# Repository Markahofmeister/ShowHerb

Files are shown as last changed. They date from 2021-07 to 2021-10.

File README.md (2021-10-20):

# ShowHerb 

ShowHerb is an automated garden watering system. It uses Adafruit's STEMMA I2C soil sensors, reporting soil moisture levels and temperature. 

The control structure uses an Arduino nano, as well as a TCA I2C multiplexer to allow up to 8 sensors to be added. The electromechanical irrigation valve is controlled by a 5V relay, also controlled by the Arduino.

## System Diagram: 

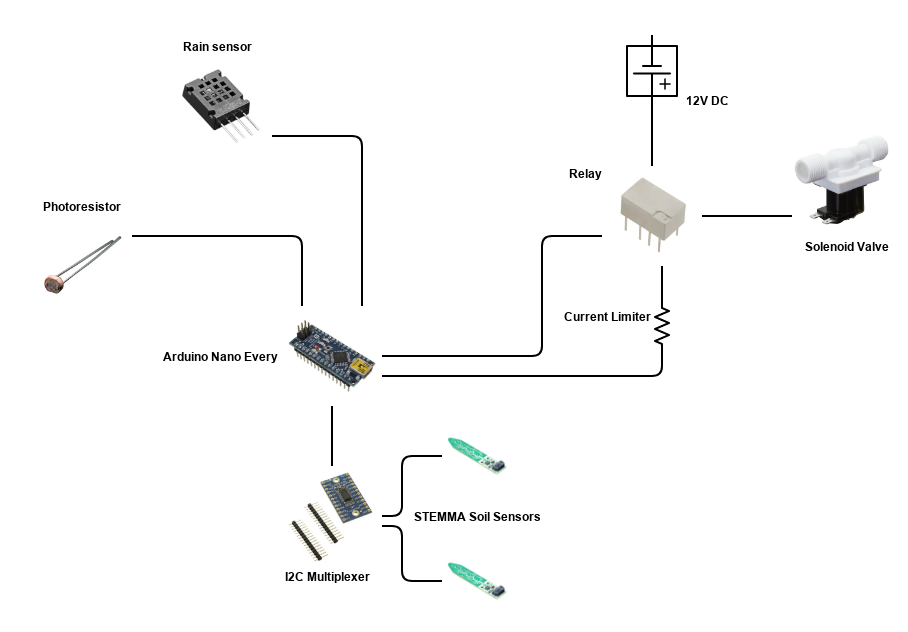
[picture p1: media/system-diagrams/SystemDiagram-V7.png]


## Code Structure: 

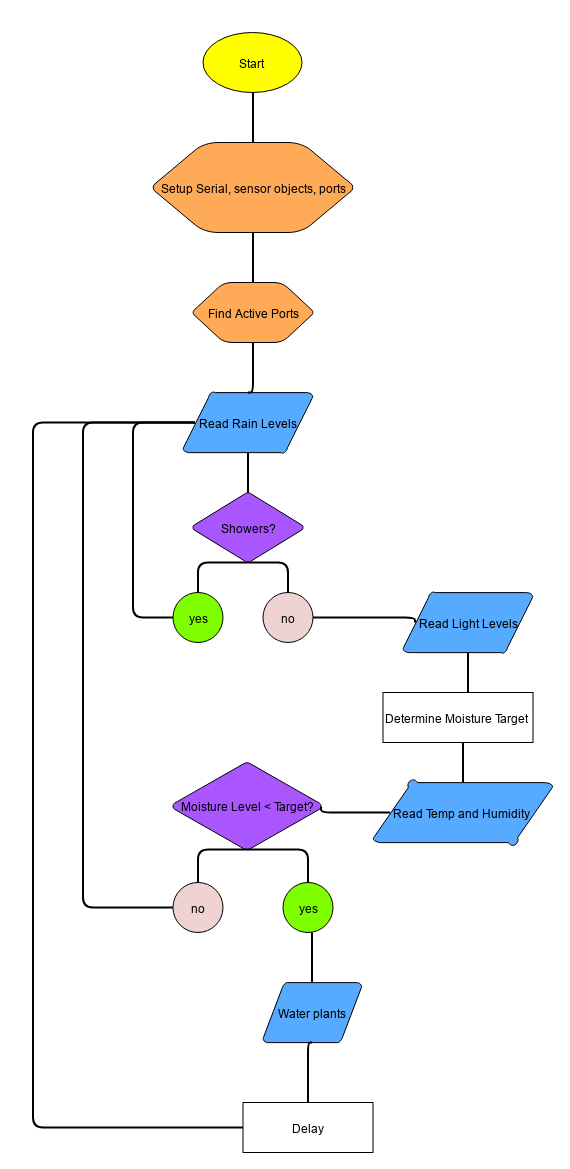
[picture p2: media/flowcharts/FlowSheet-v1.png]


The Stemma Soil Sesors have custom 3d printed covers to protect their circuitry. Additionally, the control box is custom 3D printed to allow for clean and precise wiring organization, as are the peripheral sensor housings.

Further details are available on my website [here.](https://www.markhofmeister.com/showherb)

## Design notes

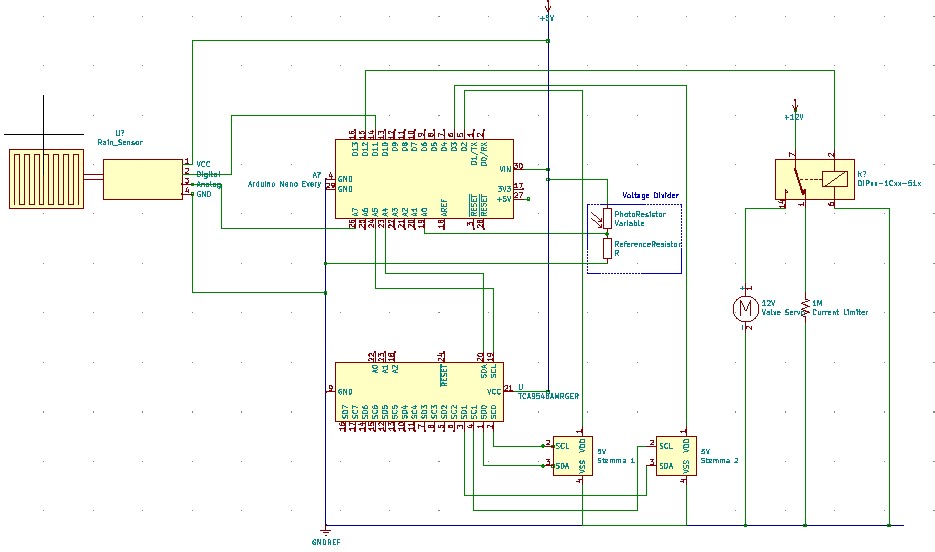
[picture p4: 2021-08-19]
media/images/Schematic.jpg

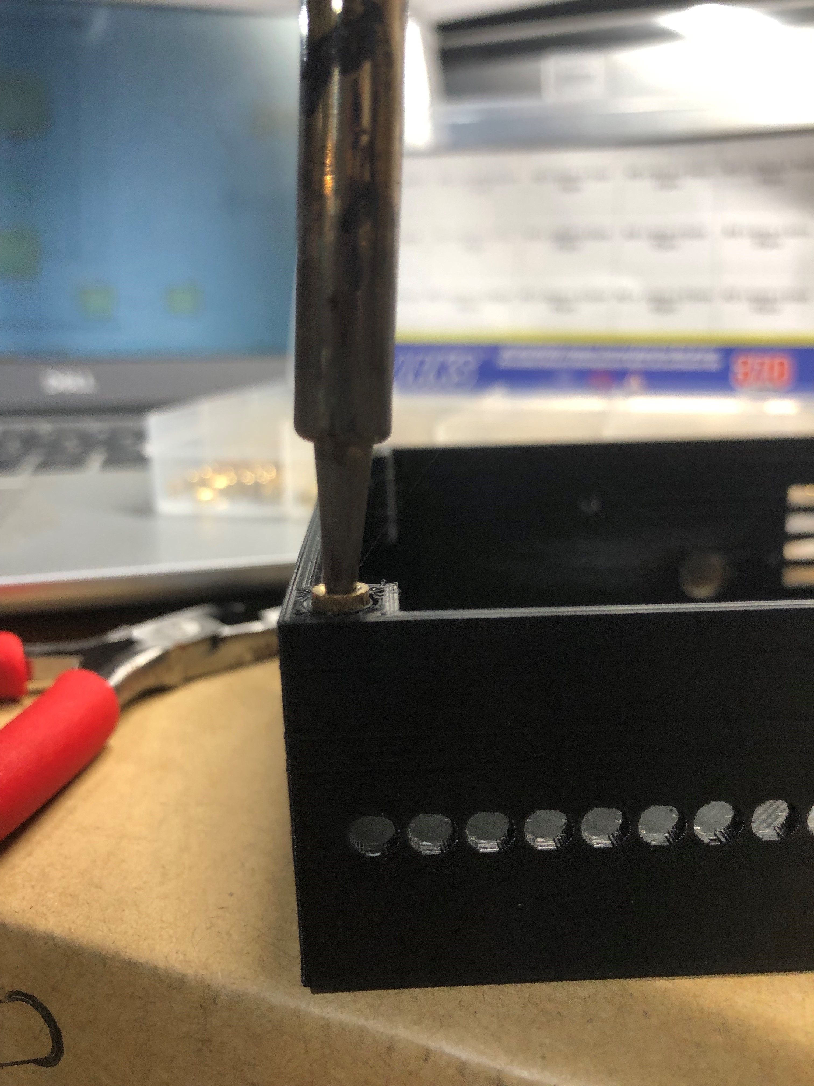
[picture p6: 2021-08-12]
media/images/Threaded-Insert.jpg

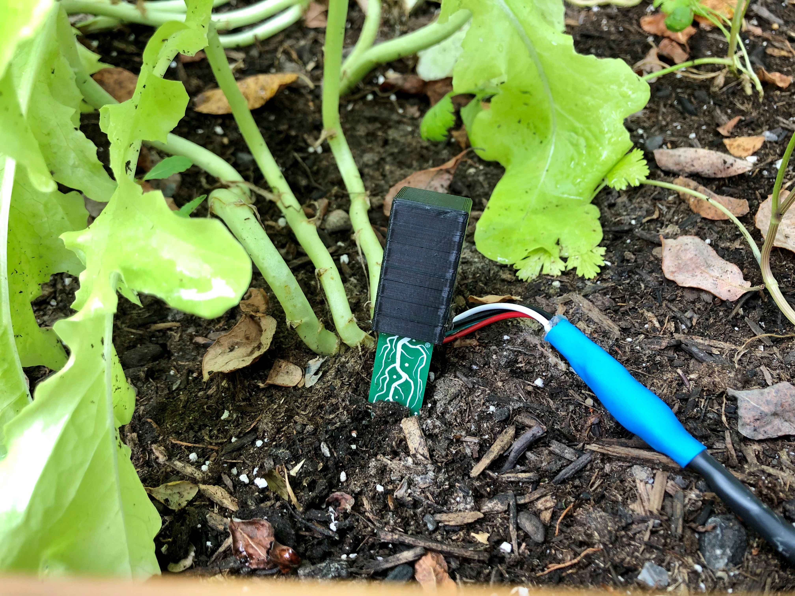
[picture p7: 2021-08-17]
media/images/Soil-Sensor-2.jpg

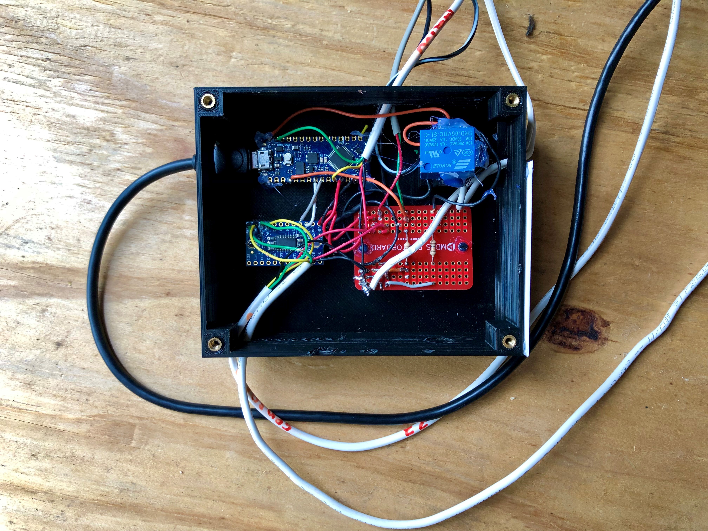
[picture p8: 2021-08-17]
media/images/Fully-Wired-Control-Box.jpg

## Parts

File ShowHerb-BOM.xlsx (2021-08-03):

Item | Source | Quantity | price | total price | product link | Project Total
Arduino Nano Every | Amazon | 3 | $10.00 | $30.00 | https://www.amazon.com/gp/product/B07YQ56B6Q/ref=ppx_yo_dt_b_asin_title_o04_s00?ie=UTF8&psc=1 | $135.20
Adafruit I2C Multiplexer | Amazon | 1 | $8.50 | $8.50 | https://www.amazon.com/gp/product/B017C09ETS/ref=ppx_yo_dt_b_asin_title_o00_s00?ie=UTF8&psc=1
STEMMA Soil Sensor | Adafruit | 2 | $7.50 | $15.00 | https://www.adafruit.com/product/4026
12V 1/2'' Electric Solenoid Valve | Amazon | 1 | $13.00 | $13.00 | https://www.amazon.com/gp/product/B07NWCRM75/ref=ppx_yo_dt_b_asin_title_o01_s00?ie=UTF8&psc=1
5V Relay | Elegoo Kit | 1 | $0.00 | $0.00
MBSS Solderable Breadboard Pack | Amazon | 1 | $21.70 | $21.70 | https://www.amazon.com/gp/product/B082PX1GKT/ref=ppx_yo_dt_b_asin_title_o03_s00?ie=UTF8&psc=1
Glarks M3-M5 Female Threaded/Knurled Inserts | Amazon | 1 | $18.00 | $18.00 | https://www.amazon.com/gp/product/B07L96KVP3/ref=ppx_yo_dt_b_asin_title_o02_s00?ie=UTF8&psc=1
Virgue M3-M5 Hex Socket Button Cap Screws | Amazon | 1 | $23.00 | $23.00 | https://www.amazon.com/gp/product/B07HVRJW5J/ref=ppx_od_dt_b_asin_title_s00?ie=UTF8&psc=1
Photoresistor | Elegoo Kit | 2 | $0.00 | $0.00
Teyleten Rain Sensor | Amazon | 3 | $2.00 | $6.00 | https://www.amazon.com/gp/product/B088FXM2JG/ref=ppx_yo_dt_b_asin_title_o01_s00?ie=UTF8&psc=1
Hatchbox PLA | Amazon | 1 |  | $0.00 | https://www.amazon.com/gp/product/B00J0ECR5I/ref=ppx_yo_dt_b_search_asin_title?ie=UTF8&psc=1
 |  |  |  | $0.00
 |  |  |  | $0.00
 |  |  |  | $0.00
 |  |  |  | $0.00
 |  |  |  | $0.00
 |  |  |  | $0.00
 |  |  |  | $0.00
 |  |  |  | $0.00
 |  |  |  | $0.00
 |  |  |  | $0.00
 |  |  |  | $0.00
 |  |  |  | $0.00
 |  |  |  | $0.00
 |  |  |  | $0.00
 |  |  |  | $0.00
 |  |  |  | $0.00
 |  |  |  | $0.00
 |  |  |  | $0.00
 |  |  |  | $0.00
 |  |  |  | $0.00
 |  |  |  | $0.00
 |  |  |  | $0.00
 |  |  |  | $0.00
 |  |  |  | $0.00
 |  |  |  | $0.00
 |  |  |  | $0.00
 |  |  |  | $0.00
 |  |  |  | $0.00
 |  |  |  | $0.00
 |  |  |  | $0.00
 |  |  |  | $0.00
 |  |  |  | $0.00
 |  |  |  | $0.00
 |  |  |  | $0.00
 |  |  |  | $0.00
 |  |  |  | $0.00
 |  |  |  | $0.00
 |  |  |  | $0.00
 |  |  |  | $0.00
 |  |  |  | $0.00
 |  |  |  | $0.00
 |  |  |  | $0.00
 |  |  |  | $0.00
 |  |  |  | $0.00
 |  |  |  | $0.00
 |  |  |  | $0.00
 |  |  |  | $0.00
 |  |  |  | $0.00
 |  |  |  | $0.00
 |  |  |  | $0.00
 |  |  |  | $0.00
 |  |  |  | $0.00
 |  |  |  | $0.00
 |  |  |  | $0.00
 |  |  |  | $0.00
 |  |  |  | $0.00
 |  |  |  | $0.00
 |  |  |  | $0.00
 |  |  |  | $0.00
 |  |  |  | $0.00
 |  |  |  | $0.00
 |  |  |  | $0.00
 |  |  |  | $0.00
 |  |  |  | $0.00
 |  |  |  | $0.00
 |  |  |  | $0.00
 |  |  |  | $0.00
 |  |  |  | $0.00
 |  |  |  | $0.00
 |  |  |  | $0.00
 |  |  |  | $0.00
 |  |  |  | $0.00
 |  |  |  | $0.00
 |  |  |  | $0.00
 |  |  |  | $0.00
 |  |  |  | $0.00
 |  |  |  | $0.00
 |  |  |  | $0.00
 |  |  |  | $0.00
 |  |  |  | $0.00
 |  |  |  | $0.00
 |  |  |  | $0.00
 |  |  |  | $0.00
 |  |  |  | $0.00
 |  |  |  | $0.00
 |  |  |  | $0.00
 |  |  |  | $0.00
 |  |  |  | $0.00

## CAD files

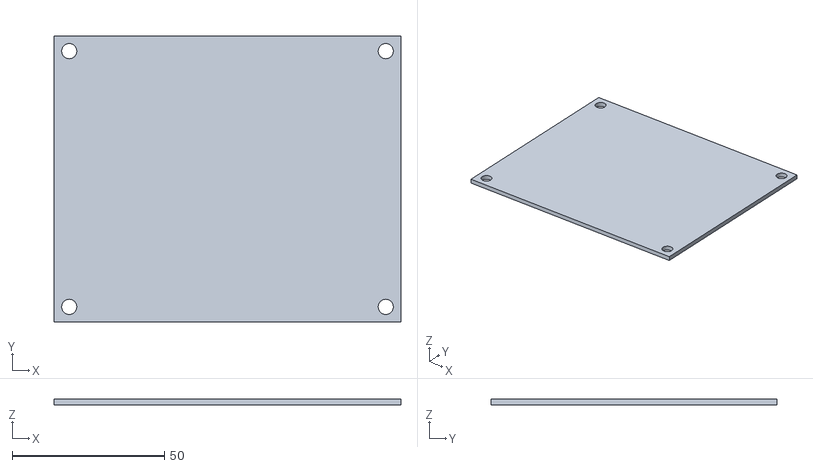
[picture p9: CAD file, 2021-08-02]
fab-Files/Ceiling-Plate/CeilingPlate.stl
114.0 x 94.0 x 2.00

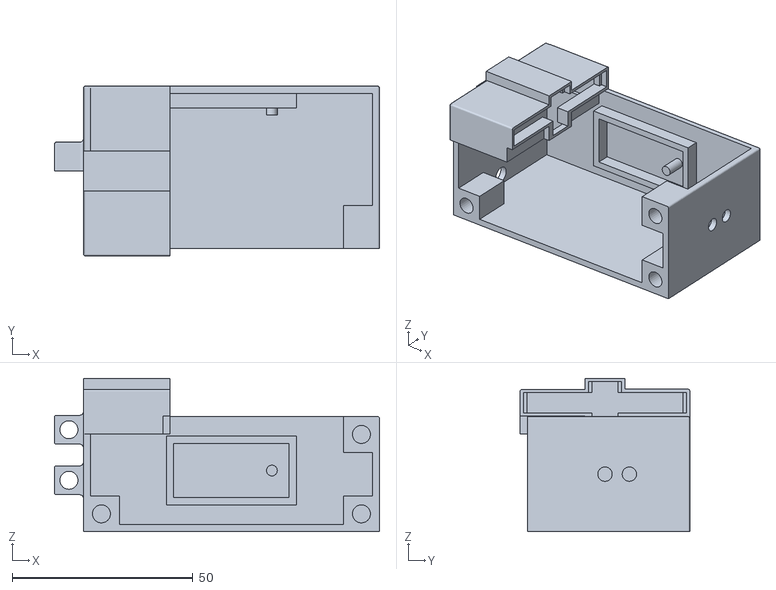
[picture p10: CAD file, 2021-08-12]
fab-Files/Rain-Sensor/ComparatorHouse-v1.stl
90.0 x 47.0 x 42.5

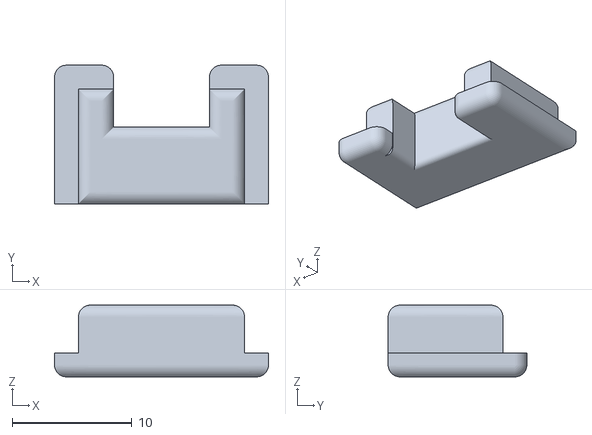
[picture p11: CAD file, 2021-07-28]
fab-Files/Stemma-Models/CoverPlug-v3.stl
17.9 x 11.6 x 6.00

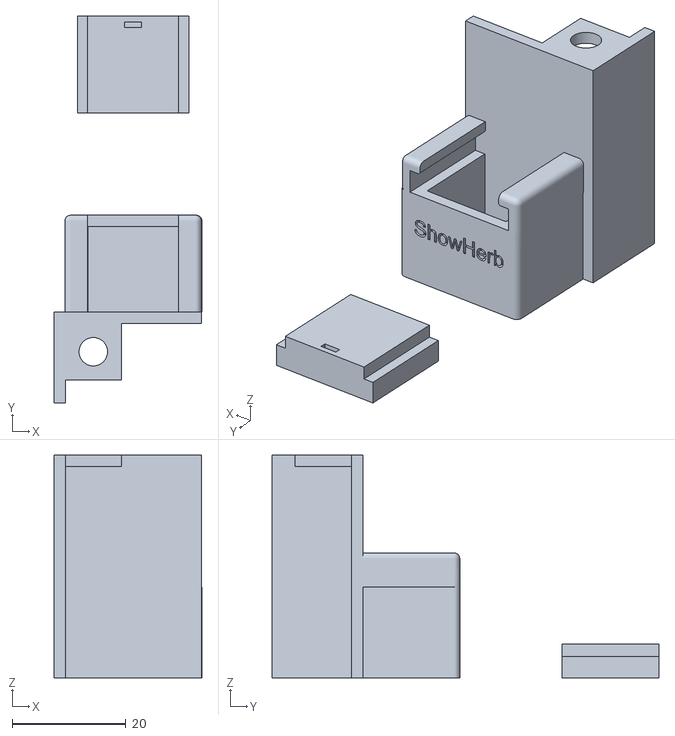
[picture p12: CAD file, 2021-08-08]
fab-Files/Storage-Box/StorageBox-v2.stl
26.0 x 68.0 x 39.2

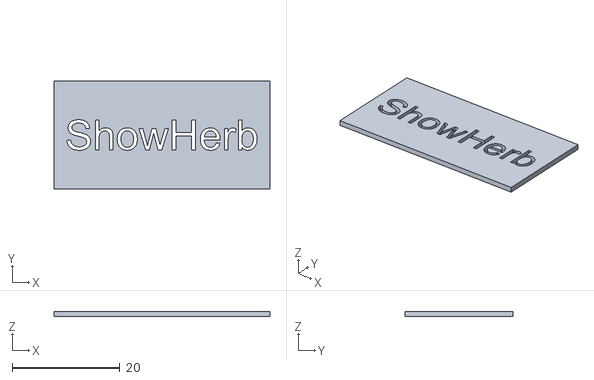
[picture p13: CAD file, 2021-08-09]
fab-Files/Text/Text-v2.stl
40.0 x 20.0 x 1.00

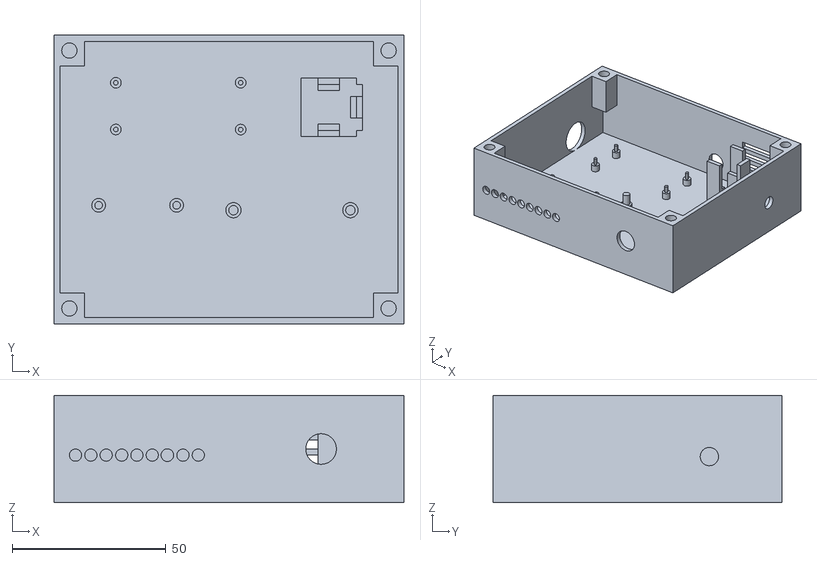
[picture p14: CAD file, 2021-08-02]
fab-Files/Base-Plate/BasePlate-v3.stl
114.0 x 94.0 x 35.0

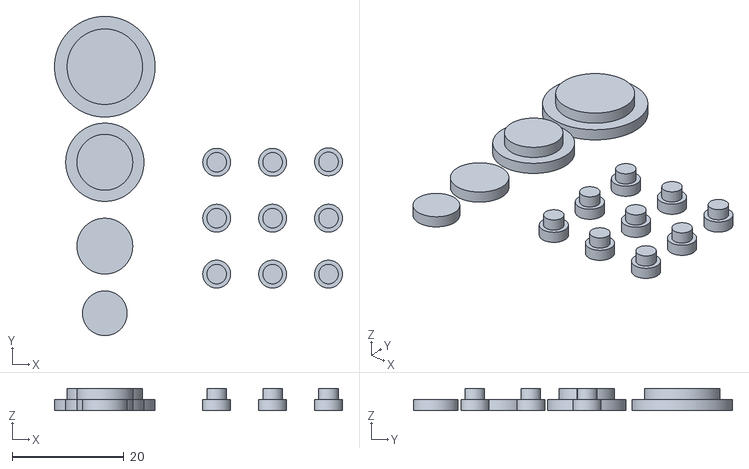
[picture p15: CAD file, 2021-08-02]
fab-Files/Plugs/ControlBoardPlugs-v2.stl
51.5 x 57.1 x 4.00

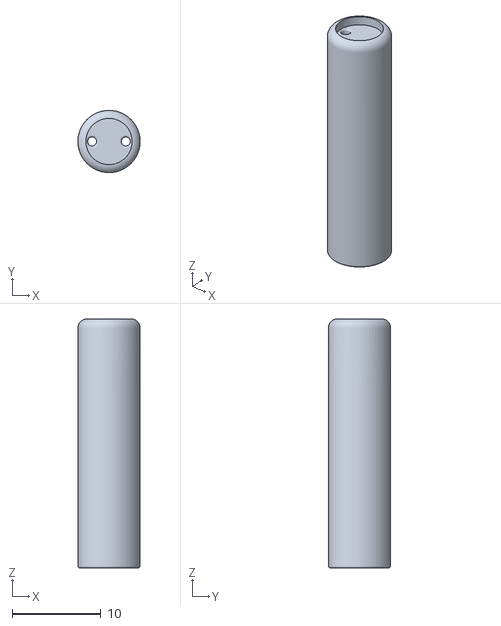
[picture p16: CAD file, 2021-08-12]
fab-Files/Photocell/Tube-v1.stl
7.00 x 7.00 x 28.0

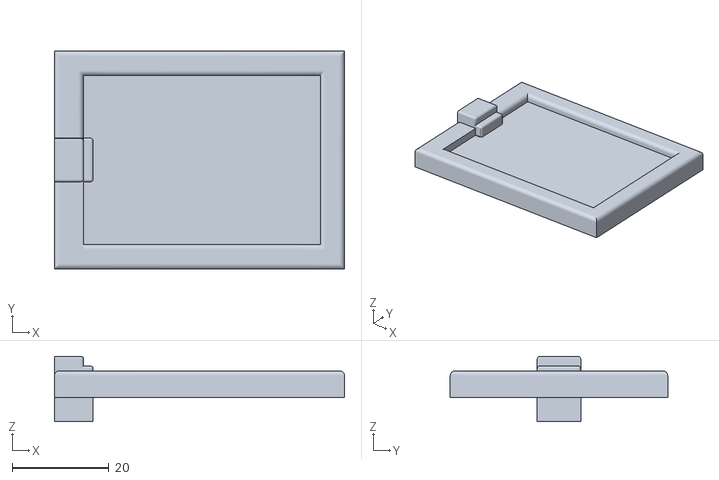
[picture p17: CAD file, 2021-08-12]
fab-Files/Rain-Sensor/PanelSheath-v1.stl
60.0 x 45.0 x 13.5

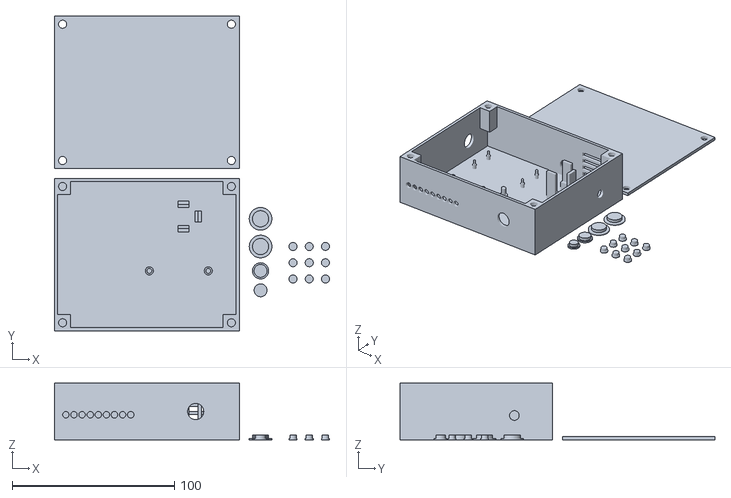
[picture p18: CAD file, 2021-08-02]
fab-Files/Base-Plate/ControlBox-Guess.stl
169.5 x 194.0 x 35.0

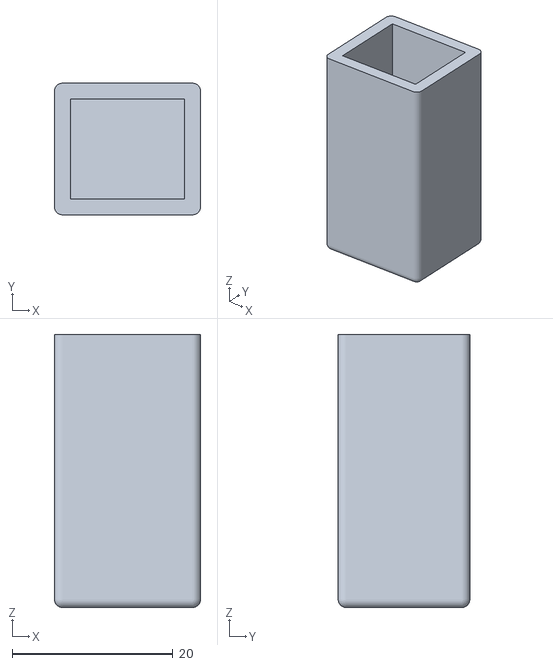
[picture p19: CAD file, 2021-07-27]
fab-Files/Stemma-Models/SensorCover-v2.stl
18.2 x 16.4 x 34.0

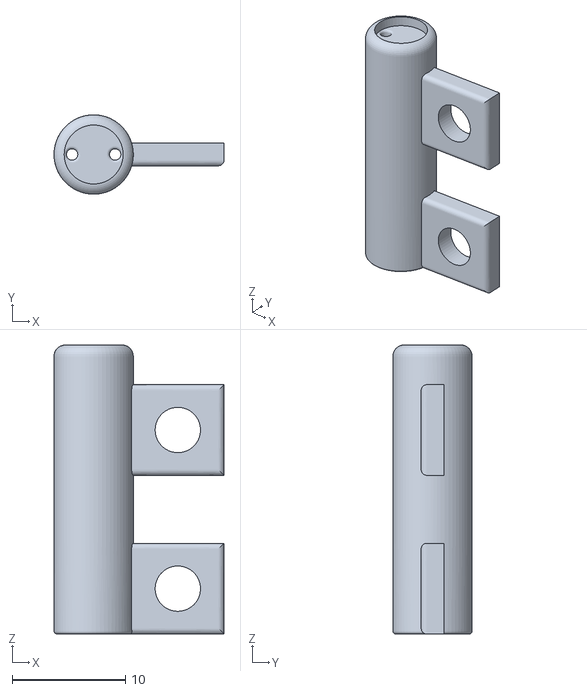
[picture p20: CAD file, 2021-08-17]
fab-Files/Photocell/TubeWithScrewholes-v2.stl
15.0 x 7.00 x 25.5

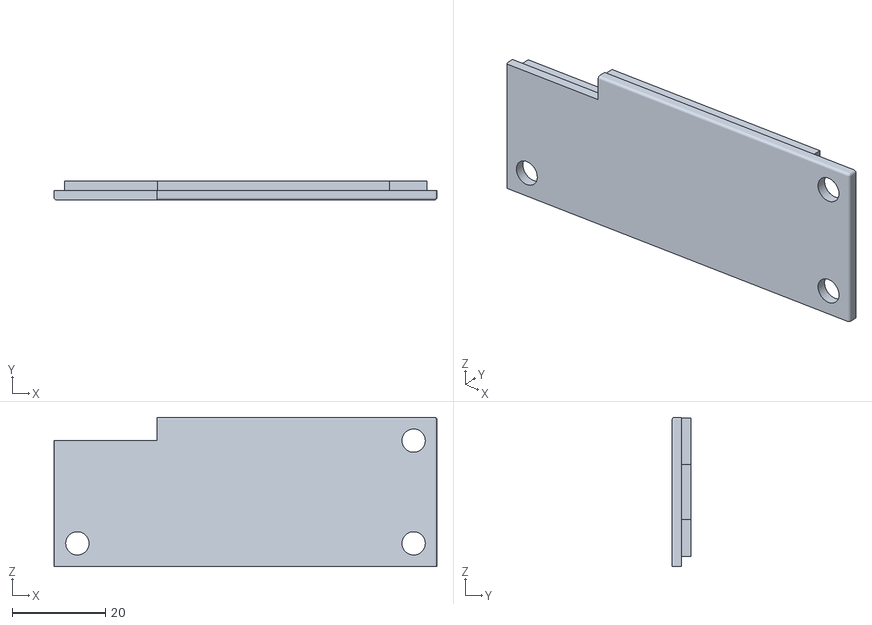
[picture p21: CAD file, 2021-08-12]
fab-Files/Rain-Sensor/ScrewPanel-v1.stl
82.0 x 4.00 x 32.0

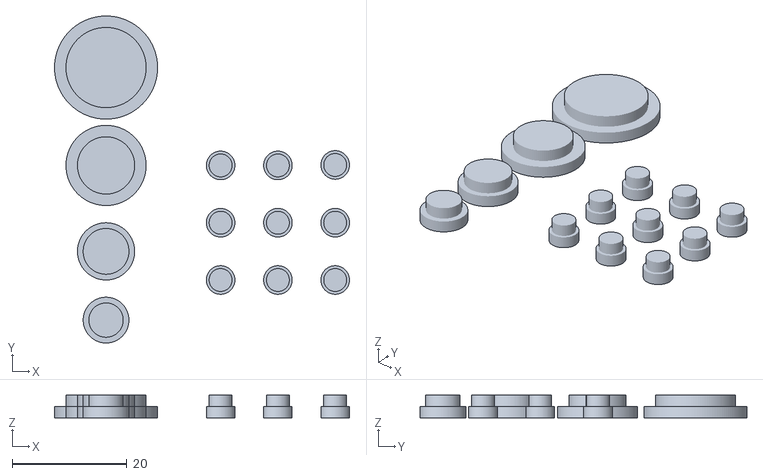
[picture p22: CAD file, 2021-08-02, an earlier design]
fab-Files/Plugs/ControlBoardPlugs-v1.stl
51.5 x 57.1 x 4.00

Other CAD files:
fab-Files/Base-Plate/BasePlate-v2.stl
fab-Files/Stemma-Models/CoverPlug-v2.stl
fab-Files/Storage-Box/StorageBox-v1.stl
fab-Files/Text/Text-v1.stl
fab-Files/Base-Plate/BasePlate-v1.stl
fab-Files/Photocell/TubeWithScrewholes-v1.stl
fab-Files/Stemma-Models/CoverPlug-v1.stl
fab-Files/Stemma-Models/SensorCover-v1.stl

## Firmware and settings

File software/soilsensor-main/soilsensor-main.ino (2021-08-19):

/**
 * TCA9548 I2CScanner.ino -- I2C bus scanner for Arduino
 *
 * Based on https://playground.arduino.cc/Main/I2cScanner/
 * 
 * Sketch to read Serial outputs for testing purposes 
 *
 */

#include "Wire.h"
#include "Adafruit_seesaw.h"

//soil sensor 
Adafruit_seesaw ss;
#define numSensors 2
uint8_t relayPin = 15;

//multiplexer address
#define TCAADDR 0x70

//photocell variables
uint8_t photoPin = A0;

//rain Sensor variables 
uint8_t rainAnalogPin = A7; 
uint8_t rainDigitalPin = 14;



//select tca port to communicate with
void tcaselect(uint8_t addr) {
  if (addr > 7) return;
 
  Wire.beginTransmission(TCAADDR);
  Wire.write(1 << addr);
  Wire.endTransmission();  
}

//initialize output pins 
void initOutputPins() {
  for (int i = 5; i <= (numSensors + 4); i++) {
    pinMode(i, OUTPUT);
  }
}

//Finds active ports and connected I2C addresses 
void findActivePorts() {
  
  for (uint8_t i=0; i<8; i++) {
      tcaselect(i);
      Serial.print("TCA Port #"); Serial.println(i);

      for (uint8_t addr = 0; addr <= 127; addr++) {
          if (addr == TCAADDR) continue;

          Wire.beginTransmission(addr);
            if (!Wire.endTransmission()) {
             Serial.print("Found soil sensor at 0x");  Serial.println(addr,HEX);
           }
      }
      
    }
}

//use photoresistor to determine water frequncy 
uint16_t getTimeToCheck() {

  uint16_t timeToCheck; 
  uint16_t photoVal = analogRead(photoPin);
  Serial.print("PhotoVal: "); Serial.println(photoVal);
  
  if (photoVal > 300) {
    timeToCheck = 4000;
  }
  else if (photoVal > 200) {
    timeToCheck = 8000;
  }
  else if(photoVal > 150) {
    timeToCheck = 12000;
  }
  else if(photoVal > 100) {
    timeToCheck = 16000; 
  }
  else {
    timeToCheck = 20000;
  }

  return timeToCheck;
}

bool checkIsRaining() {

  pinMode(rainDigitalPin, OUTPUT);
  digitalWrite(rainDigitalPin, LOW);
  pinMode(rainDigitalPin, INPUT);
  bool isRaining = !(digitalRead(rainDigitalPin));

  return isRaining; 
}

uint16_t getTimeToWater() {

  uint16_t timeToWater;
  uint16_t rainVal = analogRead(rainAnalogPin);
  Serial.print("RainVal: "); Serial.println(rainVal);
  
  if (rainVal > 850) {
    timeToWater = 5000;
  }
  else if (rainVal > 700) {
    timeToWater = 4000;
  }
  else if(rainVal > 550) {
    timeToWater = 3000;
  }
  else if(rainVal > 400) {
    timeToWater = 2000; 
  }
  else {
    timeToWater = 1000;
  }

  return timeToWater;
}


// standard setup
void setup() {

    //initialize outputs
    initOutputPins();  
  
    //begin Serial
    Serial.begin(9600);
    while (!Serial);
    delay(1000);

    //initialize Wire and sensor objects
    Wire.begin();
    

    pinMode(relayPin, OUTPUT);
    
    Serial.println("\nTCAScanner ready.");
    Serial.println("Soil Sensor(s) ready");

    //Find connected I2C addresses
    findActivePorts(); 
    
    Serial.println("\ndone");
    
}

void loop() 
{

  bool isRaining = checkIsRaining();
  uint16_t timeToWater = getTimeToWater();
  uint16_t timeToCheck = getTimeToCheck();
  Serial.print("Is raining: "); Serial.println(isRaining);
  Serial.print("Time to Water: "); Serial.println(timeToWater);
  Serial.print("Time to Check: "); Serial.println(timeToCheck);

  if(!isRaining) {

      for (uint8_t x = 0; x <= (numSensors - 1); x++) {
        ss.begin(0x36);
        uint8_t pinNum = x + 5;
        digitalWrite(pinNum, HIGH);
        Serial.println("Sensor ON");
        delay(100);
        tcaselect(x);
        delay(100);
    
        float temp = ss.getTemp();
        delay(100);
        uint16_t capread = ss.touchRead(0);
        delay(100);

        if (capread > 2500) {
          capread = 1000;
        }
        
        //Serial.print("Photocell Frequency: "); Serial.println(getPhotoVal);
        //Serial.print("Rain Sensor Frequency: "); Serial.println(getRainVal);
        Serial.print("Sensor "); Serial.print(x + 1); Serial.print(" Capacitive: "); Serial.println(capread);
        Serial.print("Sensor "); Serial.print(x + 1); Serial.print(" Temperature: "); Serial.println(temp);
    
        if(capread < 1200) {
           digitalWrite(relayPin, HIGH);
           Serial.println("Valve Open");
           delay(timeToWater);
           digitalWrite(relayPin, LOW);
           Serial.println("Valve Closed");
           delay(10000);
         }else {
           //continue; 
         }
    
        digitalWrite(pinNum, LOW);
        Serial.println("Sensor OFF");
        delay(timeToCheck);
    
      }
   }
   delay(1000);
}













/*uint16_t getTotalFreq() {
  
  uint16_t totalVal, totalFreq;
  uint8_t photoVal = getPhotoVal();
  uint8_t rainVal = getRainVal();

  totalVal = photoVal + rainVal;
  
  if (totalVal > 900) {
    totalFreq = 5000;
  }
  else if (totalVal > 750) {
    totalFreq = 4000;
  }
  else if(totalVal > 600) {
    totalFreq = 3000;
  }
  else if(totalVal > 450) {
    totalFreq = 2000; 
  }
  else {
    totalFreq = 1000;
  }
  
  return totalFreq;
}*/

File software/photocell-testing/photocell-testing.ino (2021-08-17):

/*Date: 08/09/2021
 * 
 * Photocell analog return value testing code 
 * 
 */

 uint8_t analogValue;
 uint8_t analogPin = A0;

 void setup() {
  
  Serial.begin(9600);

 }

void loop() {
  analogValue = analogRead(analogPin);

  Serial.println(analogValue);
  delay(500);
}

/*
 * Sunny day outside: ~250 return 
 * Sunny day inside, no lights: ~125 return 
 * Night time outside: 
 */

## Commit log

2021-07-25 Initial File Commit
    [ShowHerb-Item-List.xlsx]
2021-07-25 Initial Schematic, Item list update
    [ShowHerb-Item-List.xlsx]
2021-07-27 Add v2 cover, c+p.cmd
    [SensorCover-v1.stl, SensorCover-v2.stl]
2021-07-27 Added coverplug 3D print files
    [CoverPlug-v1.stl, CoverPlug-v2.stl]
2021-07-28 Added Cover Plug v3
    [CoverPlug-v3.stl]
2021-07-31 Added schematic images, software + testing files
2021-08-02 Added soilsensor main Serial testing file, nano pinout diagrams, first version of control box.
    [Control-box-test.stl]
2021-08-02 Added multiple .stl print files, created KiCad directory
    [BasePlate-Guess.stl, CeilingPlate.stl, Control-box-test.stl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]
2021-08-02 Added new 3D models, organization. Update README a bit.
    [BasePlate-v1.stl, BasePlate-v2.stl, BasePlate-v3.stl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]
2021-08-03 Added to item list, added multiple 3D models, update main testing code.
    [CeilingPlate.stl, ShowHerb-Item-List.xlsx, StorageBox-v1.stl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]
2021-08-08 Added rain sensor and photoresistor to schematic, v2 storage box
    [ShowHerb-Schematic.sch, StorageBox-v2.stl]
2021-08-09 Added filler text
    [Text-v2.stl]
2021-08-09 Modified main Serial testing code with photocell changes
    [ShowHerb-Schematic.sch]
2021-08-09 Added rain sensor testing code
2021-08-09 Added rain sensor testing code mods
2021-08-09 Added rain sensor to main code
2021-08-12 Added organization to fab-files directory, added rain/photocell sensor fabrication files
    [BasePlate-v1.stl, BasePlate-v2.stl, BasePlate-v3.stl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]
2021-08-12 Changed to BOM name
    [ShowHerb-BOM.xlsx]
2021-08-12 Fixed pinning error in schematic/software
    [ShowHerb-Schematic.sch]
2021-08-17 Added more testing code mods
    [TubeWithScrewholes-v2.stl]
2021-08-19 Added schematic image
2021-09-08 Fix .gitignore, add footprint file
